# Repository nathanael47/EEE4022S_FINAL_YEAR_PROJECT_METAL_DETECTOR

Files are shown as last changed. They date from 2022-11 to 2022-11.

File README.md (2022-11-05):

# EEE4022S_FINAL_YEAR_PROJECT_METAL_DETECTOR
This is the git repository for all code my design and implementation of a metal detector

# PROJECT NAME: DESIGN AND IMPLEMENTATION OF A METAL DETECTOR

# DESCRIPTION:
This is the design and implementation of a metal detector that can detect metals and distinguish if it is ferrous or non ferrous

# INSTALLATION
1. Download the zip version of the repository.
2. Alternatively, pull the repository using the following line;

# USAGE
Prototype:
1. Install arduino and teensyduino
2. Run any of the implementations.
3. Run Metal_Detector.ino

# CREDITS: Done by NATHANAEL GEORGE THOMAS-5/11/2022

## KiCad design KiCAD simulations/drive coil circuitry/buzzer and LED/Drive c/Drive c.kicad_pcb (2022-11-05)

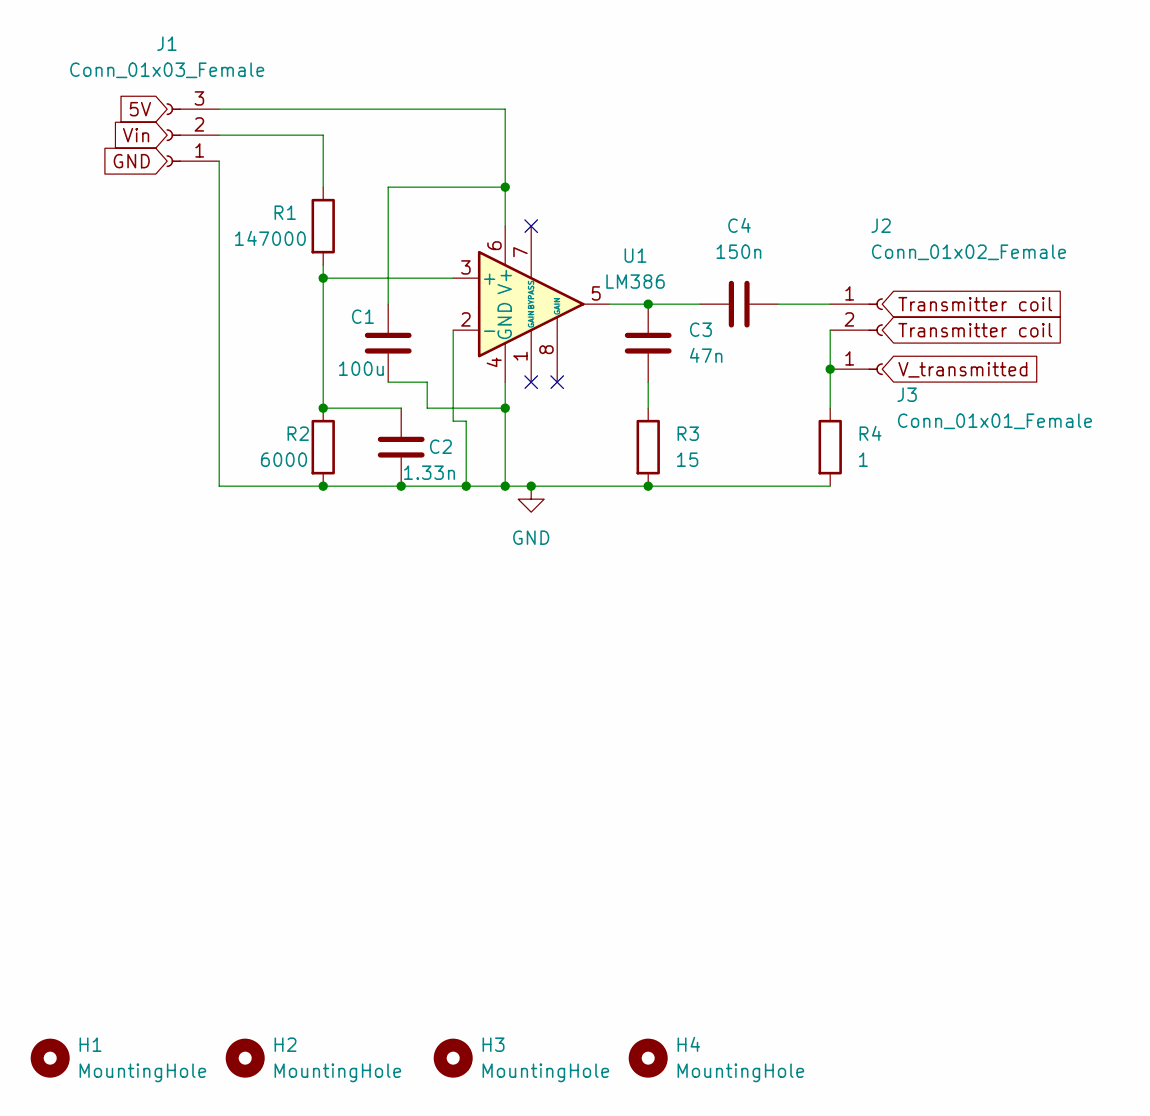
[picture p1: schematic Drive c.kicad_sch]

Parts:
C1: 100u; CP_Radial_D7.5mm_P2.50mm
C2: 1.33n; CP_Radial_D7.5mm_P2.50mm
C3: 47n; CP_Radial_D7.5mm_P2.50mm
C4: 150n; CP_Radial_D7.5mm_P2.50mm
H1, H2, H3, H4: MountingHole; MountingHole_2.7mm_M2.5_ISO14580_Pad_TopOnly
J1: Conn_01x03_Female; PinSocket_1x03_P2.54mm_Vertical
J2: Conn_01x02_Female; PinSocket_1x02_P2.54mm_Vertical
J3: Conn_01x01_Female; PinSocket_1x01_P2.54mm_Vertical
R1: 147000; R_Axial_DIN0309_L9.0mm_D3.2mm_P12.70mm_Horizontal
R2: 6000; R_Axial_DIN0309_L9.0mm_D3.2mm_P12.70mm_Horizontal
R3: 15; R_Axial_DIN0309_L9.0mm_D3.2mm_P12.70mm_Horizontal
R4: 1; R_Axial_DIN0309_L9.0mm_D3.2mm_P12.70mm_Horizontal
U1: LM386; DIP-8_W7.62mm

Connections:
GND: C1.2, C2.2, J1.1, R2.2, R3.2, R4.2, U1.2 (-), U1.4 (GND)
unnamed: C1.1, J1.3, U1.6 (V+)
unnamed: C2.1, R1.2, R2.1, U1.3 (+)
unnamed: C3.1, R3.1
unnamed: C3.2, C4.1, U1.5
unnamed: C4.2, J2.1
unnamed: J1.2, R1.1
unnamed: J2.2, J3.1, R4.1

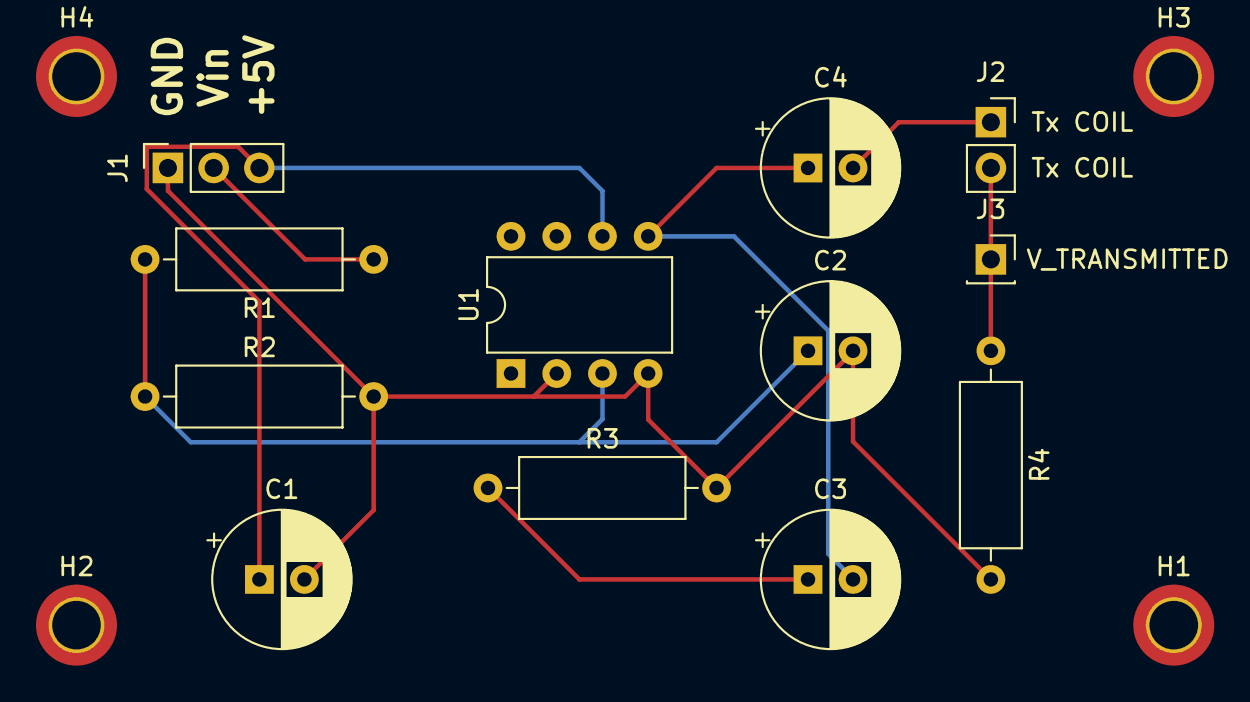
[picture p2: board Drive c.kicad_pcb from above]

Board: 2 copper layers, 16 parts (0 on the bottom side), 8 nets.

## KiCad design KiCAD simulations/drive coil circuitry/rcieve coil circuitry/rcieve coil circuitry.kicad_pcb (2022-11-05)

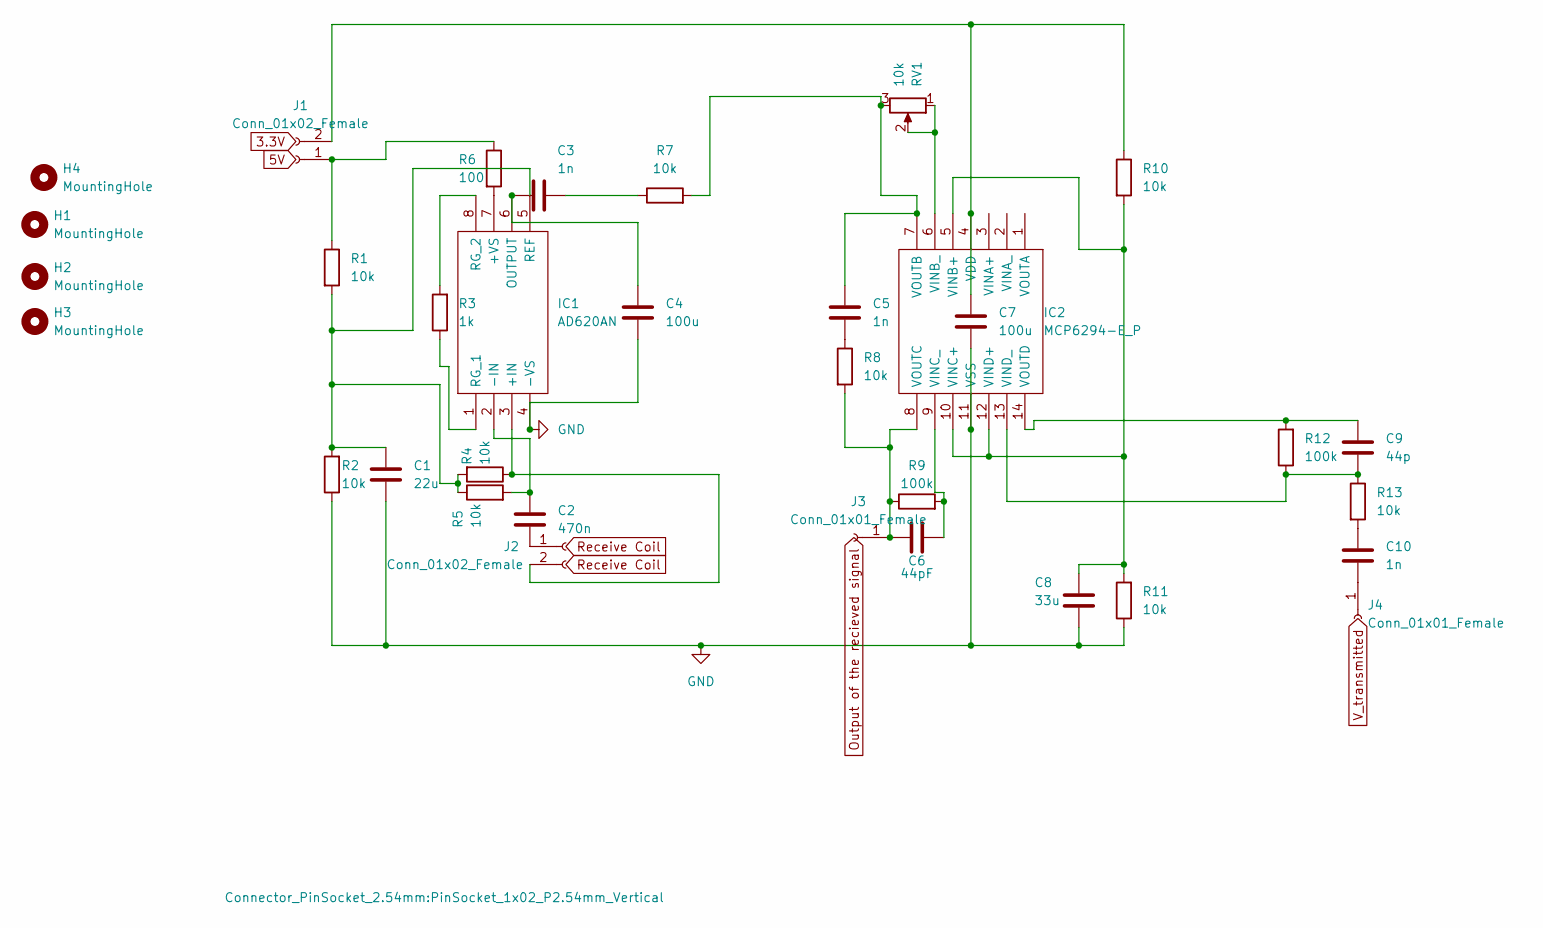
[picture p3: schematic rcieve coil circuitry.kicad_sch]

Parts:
C1: 22u; C_Rect_L4.6mm_W3.8mm_P2.50mm_MKS02_FKP02
C2: 470n; C_Rect_L7.0mm_W4.5mm_P5.00mm
C3: 1n; C_Rect_L7.0mm_W6.5mm_P5.00mm
C4: 100u; C_Radial_D10.0mm_H12.5mm_P5.00mm
C5: 1n; C_Rect_L4.6mm_W3.0mm_P2.50mm_MKS02_FKP02
C6: 44pF; C_Rect_L4.6mm_W2.0mm_P2.50mm_MKS02_FKP02
C7: 100u; C_Radial_D6.3mm_H5.0mm_P2.50mm
C8: 33u; C_Radial_D6.3mm_H5.0mm_P2.50mm
C9: 44p; C_Rect_L4.0mm_W2.5mm_P2.50mm
C10: 1n; C_Rect_L4.0mm_W2.5mm_P2.50mm
H1, H2, H3, H4: MountingHole; MountingHole_2.2mm_M2
IC1: AD620AN; DIP-8_W7.62mm_LongPads; Manufacturer_Part_Number AD620AN; Mouser Part Number 584-AD620AN
IC2: MCP6294-E_P; DIP-14_W7.62mm_LongPads; Manufacturer_Part_Number MCP6294-E/P; Mouser Part Number 579-MCP6294-E/P
J1, J2: Conn_01x02_Female; PinSocket_1x02_P2.54mm_Vertical
J3, J4: Conn_01x01_Female; PinSocket_1x01_P2.54mm_Vertical
R1, R2: 10k; R_Axial_DIN0309_L9.0mm_D3.2mm_P5.08mm_Vertical
R3: 1k; R_Axial_DIN0309_L9.0mm_D3.2mm_P5.08mm_Vertical
R4, R5, R7, R8, R10, R11: 10k; R_Axial_DIN0614_L14.3mm_D5.7mm_P15.24mm_Horizontal
R6: 100; R_Axial_DIN0614_L14.3mm_D5.7mm_P15.24mm_Horizontal
R9: 100k; R_Axial_DIN0614_L14.3mm_D5.7mm_P15.24mm_Horizontal
R12: 100k; R_Axial_DIN0414_L11.9mm_D4.5mm_P15.24mm_Horizontal
R13: 10k; R_Axial_DIN0414_L11.9mm_D4.5mm_P15.24mm_Horizontal
RV1: 10k; Potentiometer_Alps_RK09K_Single_Vertical

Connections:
GND: C1.2, C4.2, C7.2, C8.2, IC1.4 (-VS), IC2.11 (VSS), R2.1, R11.1
unnamed: C1.1, IC1.5 (REF), R1.2, R2.2, R4.2, R5.1
unnamed: C2.1, IC1.2 (-IN), R5.2
unnamed: C2.2, J2.1
unnamed: C3.1, C4.1, IC1.6 (OUTPUT)
unnamed: C3.2, R7.1
unnamed: C5.1, IC2.7 (VOUTB), R7.2, RV1.3
unnamed: C5.2, R8.1
unnamed: C6.1, IC2.8 (VOUTC), J3.1, R8.2, R9.1
unnamed: C6.2, IC2.9 (VINC_), R9.2
unnamed: C8.1, IC2.5 (VINB+), IC2.10 (VINC+), IC2.12 (VIND+), R10.2, R11.2
unnamed: C9.1, IC2.14 (VOUTD), R12.2
unnamed: C9.2, IC2.13 (VIND_), R12.1, R13.1
unnamed: C10.1, R13.2
unnamed: C10.2, J4.1
unnamed: IC1.1 (RG_1), R3.1
unnamed: IC1.3 (+IN), J2.2, R4.1
unnamed: IC1.7 (+VS), R6.2
unnamed: IC1.8 (RG_2), R3.2
unnamed: IC2.6 (VINB_), RV1.1, RV1.2
unnamed: J1.1, R1.1, R6.1
unnamed: C7.1, IC2.4 (VDD), J1.2, R10.1

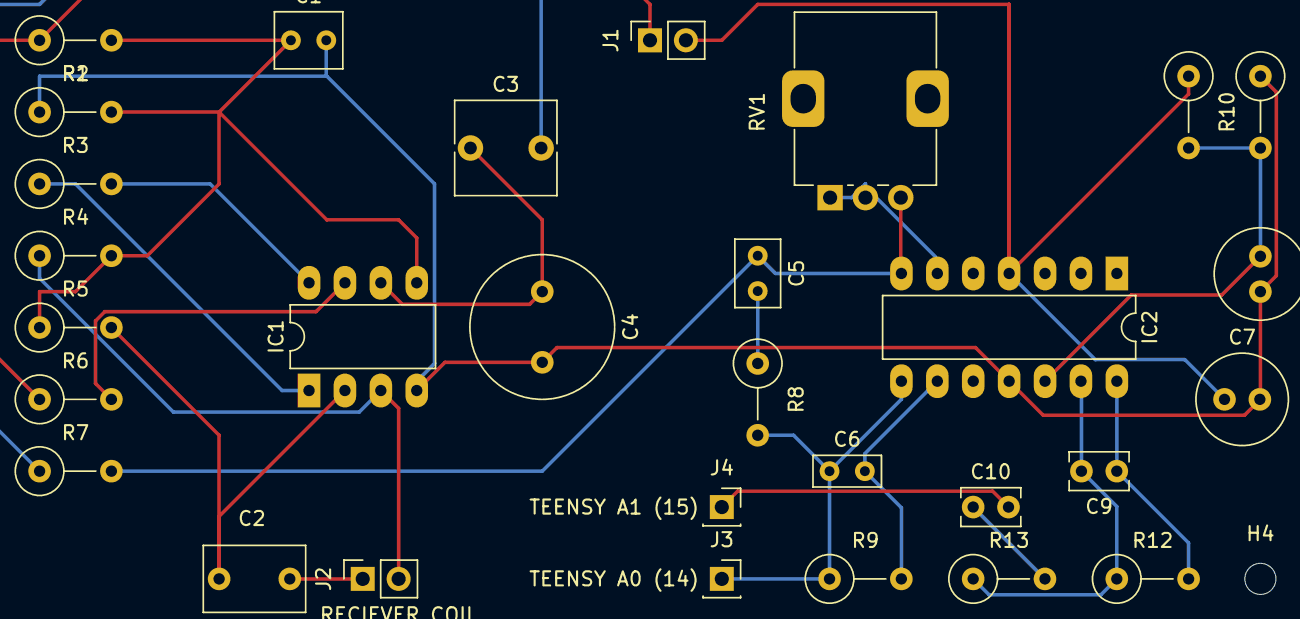
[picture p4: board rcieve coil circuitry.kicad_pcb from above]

Board: 2 copper layers, 34 parts (0 on the bottom side), 22 nets.

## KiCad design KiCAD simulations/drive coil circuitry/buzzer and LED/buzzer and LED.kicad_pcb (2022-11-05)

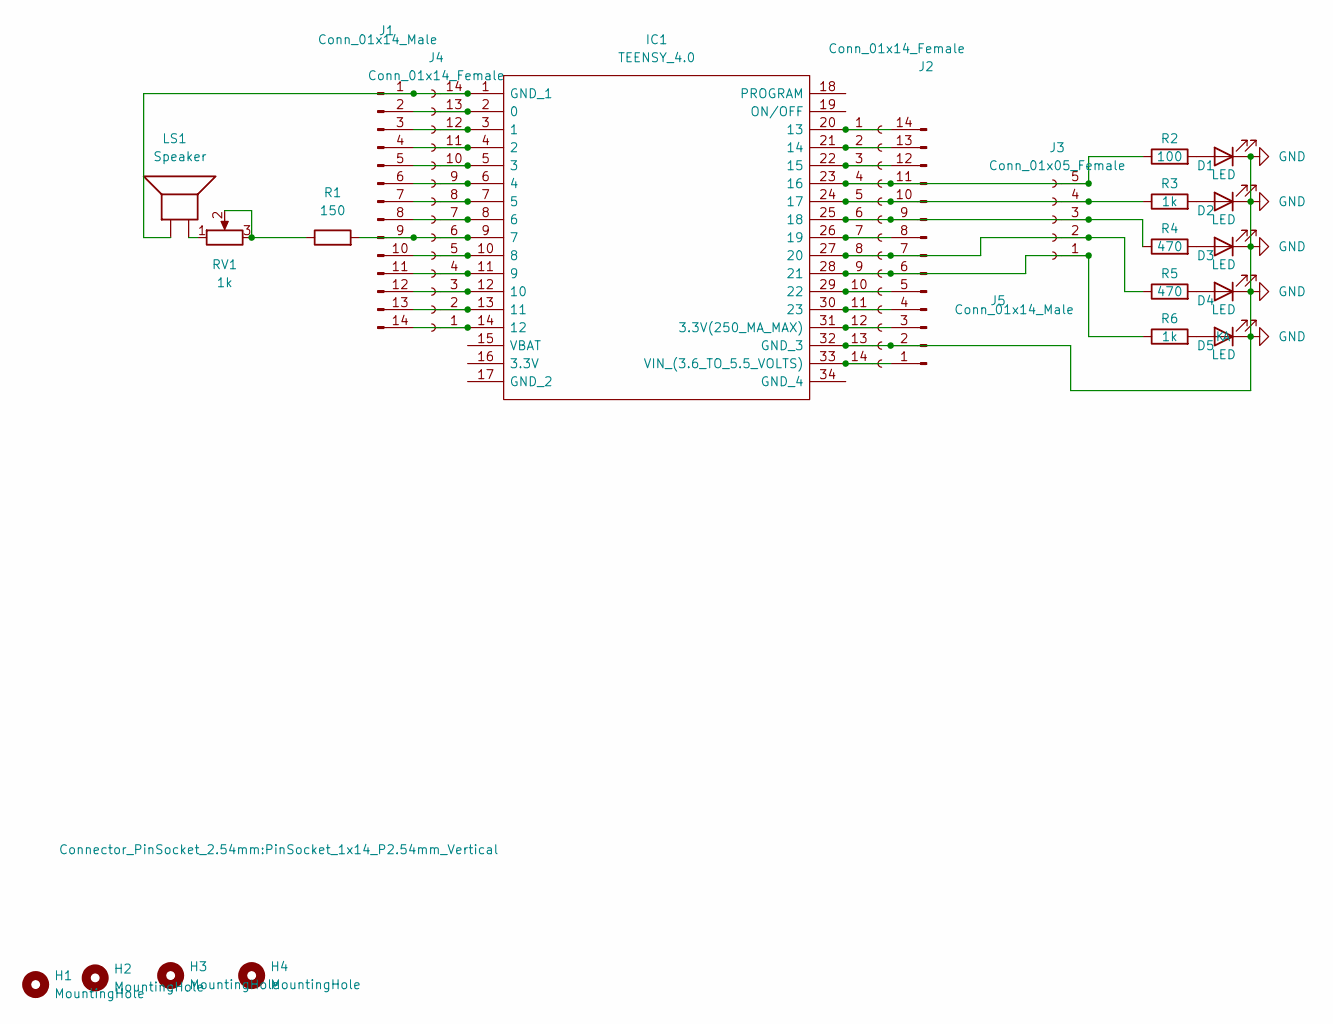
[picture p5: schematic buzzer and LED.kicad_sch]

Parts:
D1, D2, D3, D4: LED; LED_D3.0mm_Clear
D5: LED; LED_D3.0mm
H1, H2, H3, H4: MountingHole; MountingHole_2.1mm
IC1: TEENSY_4.0; TEENSY40; Manufacturer_Part_Number TEENSY 4.0
J1, J2: Conn_01x14_Male; PinHeader_1x14_P2.54mm_Vertical
J3: Conn_01x05_Female; PinSocket_1x05_P1.27mm_Vertical
J4, J5: Conn_01x14_Female; PinSocket_1x14_P2.54mm_Vertical
LS1: Speaker; Buzzer_12x9.5RM7.6
R1: 150; R_Axial_DIN0207_L6.3mm_D2.5mm_P5.08mm_Vertical
R2: 100; R_Axial_DIN0207_L6.3mm_D2.5mm_P5.08mm_Vertical
R3, R6: 1k; R_Axial_DIN0207_L6.3mm_D2.5mm_P5.08mm_Vertical
R4, R5: 470; R_Axial_DIN0207_L6.3mm_D2.5mm_P5.08mm_Vertical
RV1: 1k; Potentiometer_Alps_RK163_Single_Horizontal

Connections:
unnamed: D1.2 (A), R2.2
unnamed: D2.2 (A), R3.2
unnamed: D3.2 (A), R4.2
unnamed: D4.2 (A), R5.2
unnamed: D5.2 (A), R6.2
unnamed: IC1.1 (GND_1), J1.1, J4.14, LS1.1
unnamed: IC1.2 (0), J1.2, J4.13
unnamed: IC1.3 (1), J1.3, J4.12
unnamed: IC1.4 (2), J1.4, J4.11
unnamed: IC1.5 (3), J1.5, J4.10
unnamed: IC1.6 (4), J1.6, J4.9
unnamed: IC1.7 (5), J1.7, J4.8
unnamed: IC1.8 (6), J1.8, J4.7
unnamed: IC1.9 (7), J1.9, J4.6, R1.2
unnamed: IC1.10 (8), J1.10, J4.5
unnamed: IC1.11 (9), J1.11, J4.4
unnamed: IC1.12 (10), J1.12, J4.3
unnamed: IC1.13 (11), J1.13, J4.2
unnamed: IC1.14 (12), J1.14, J4.1
unnamed: IC1.20 (13), J2.14, J5.1
unnamed: IC1.21 (14), J2.13, J5.2
unnamed: IC1.22 (15), J2.12, J5.3
unnamed: IC1.23 (16), J2.11, J3.5, J5.4, R2.1
unnamed: IC1.24 (17), J2.10, J3.4, J5.5, R3.1
unnamed: IC1.25 (18), J2.9, J3.3, J5.6, R4.1
unnamed: IC1.26 (19), J2.8, J5.7
unnamed: IC1.27 (20), J2.7, J3.2, J5.8, R5.1
unnamed: IC1.28 (21), J2.6, J3.1, J5.9, R6.1
unnamed: IC1.29 (22), J2.5, J5.10
unnamed: IC1.30 (23), J2.4, J5.11
unnamed: IC1.31 (3.3V(250_MA_MAX)), J2.3, J5.12
unnamed: IC1.33 (VIN_(3.6_TO_5.5_VOLTS)), J2.1, J5.14
unnamed: LS1.2, RV1.1
unnamed: R1.1, RV1.2, RV1.3

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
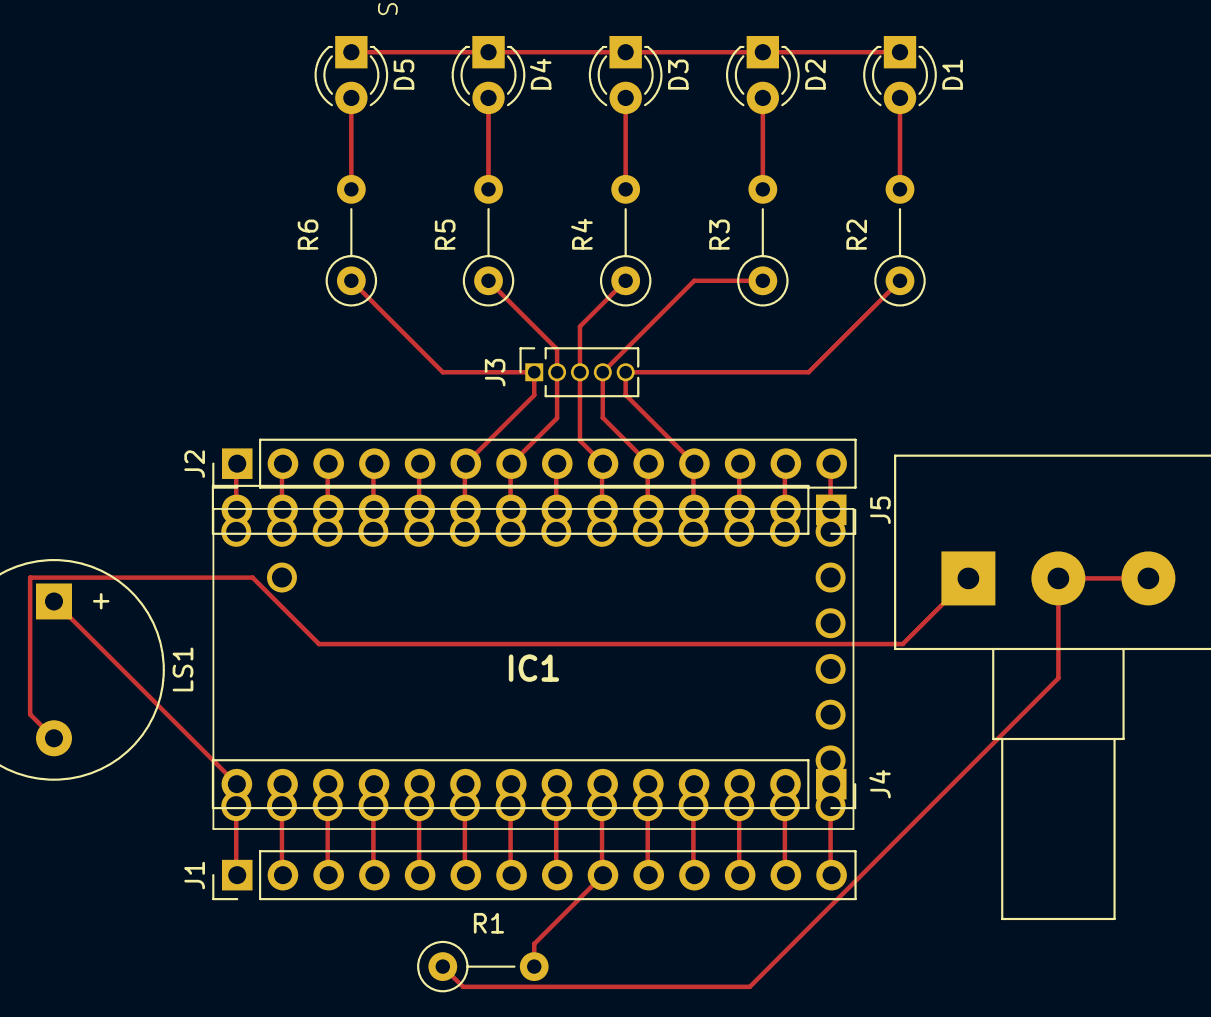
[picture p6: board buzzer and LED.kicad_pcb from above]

Board: 2 copper layers, 23 parts (0 on the bottom side), 36 nets.

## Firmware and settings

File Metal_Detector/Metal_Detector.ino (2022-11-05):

#include <ADC.h>
#include <math.h>
int n_test = 1000;                        //the number of samples we are going to take at one go 
int n; 
const int n_max = 1620;
int driveCoil = 6;                       //defining which pin the drive coil circuitry will be attached to 
//setting up the sine and cosine waves
const float pi = 3.14159267;             //initiating a value for pi 
int rA0[n_max];
int rA1[n_max];
int buzzer = 9;                          //initialising the pin on which the buzzer is attached to
float f0 = 20000;                        //setting the frequency of 20kHz 
int t0 = (1/f0)*pow(10,6);               //finding how long one cycle will take at 20kHz
float w = 2*pi*f0;

//LED pin setup 
int RLED = 18;
int OLED = 17;
int YLED = 16;
int GLED = 20;
int WLED = 21;

int noBit = 12;
//variable to store the value of I and Q for both the received and transmitted signals
//received signal 
float I_rx = 0;
float Q_rx = 0;
//transmitted signal
float I_tx = 0;
float Q_tx = 0;  

float freq;                               //variable to hold a value of frequency which is used to change the buzzers pwm frequency
float f_sample;                           //used to store the sampling frequency
float t_sample;                           //used to store the period of the sampling frequency 
float phaseShift;
float samplingTime = 10;                  //time in milliseconds

float amp_ref;                            //placeholder for the value of the reference amplitude
float phase_ref;                          //placeholder for the value of the reference phase
int nRef = 10;                            //how many times the code should run during calibration
float Iref;                               //placeholder for the value of the reference I value
float Qref;                               //placeholder for the value of the reference Q value

void setup() {
  // put your setup code here, to run once:
  
  analogWriteFrequency(driveCoil, 20000);   //setting the frequency to 20kHz 
  analogReadResolution(noBit); // Can be 8, 10, 12, 16
  analogReadAveraging(1); // can be 1, 2, 4, 8, 16 or 32
  analogReference(0); // Voltage reference
  Serial.begin(9600);

  //setting up the pinModes used in the metal detector
  pinMode(driveCoil, OUTPUT);               //setting the pin to an output       
  pinMode(A0, INPUT);                       //setting A0 as an input pin to recieve signals 
  pinMode(A1, INPUT);                       //setting A0 as an input pin to recieve a signal
  analogWrite(driveCoil, 127);              //Setting a PWM signal with a 50% duty cycle
  
  //LED setup
  pinMode(RLED, OUTPUT);
  pinMode(OLED, OUTPUT);
  pinMode(GLED, OUTPUT);
  pinMode(YLED, OUTPUT);
  pinMode(WLED, OUTPUT);
  digitalWrite(WLED, HIGH);

  //getting the sample rate frequency to be used to generate the sine and cos waves 
  for (int i =0; i<10; i++){
    f_sample = RateSampling();
  }
  t_sample = 1/f_sample;

  n = round((samplingTime*pow(10,-3))/t_sample);

  phaseShift =(f0/f_sample)*(360/2);
  ref();
//  Serial.println(amp_ref);
//  Serial.println(phase_ref); 
}

float ref(){
   amp_ref = 0; 
   phase_ref = 0; 
   for(int j=0; j<nRef; j++){
     for(int i = 0; i<n; i++){
      rA0[i] = analogRead(A0);
      rA1[i] = analogRead(A1);  
     }
     for(int j = 0; j<n; j++){
         float x_v = 3.3*(rA0[j]/pow(2,noBit))-1.65;      //converting the bit value of the received signal to a voltage
         float x_tx = 3.3*(rA1[j]/pow(2,noBit))-1.65;    //converting the bit value of the transmitted signal to a voltage
         I_rx = I_rx + x_v*(2*cos(w*j*t_sample));
         Q_rx = Q_rx + x_v*(-2*sin(w*j*t_sample));
    
         I_tx = I_tx + x_tx*(2*cos(w*j*t_sample));
         Q_tx = Q_tx + x_tx*(-2*sin(w*j*t_sample));
      }
      //Simulating a low pass filter through weighted average
      float I_filt = I_rx/n;                     //getting the weighted average of the I for the recieved signal.  
      float Q_filt = Q_rx/n;                     //getting the weighted average of the Q for the recieved signal. 
    
      float I_filt_tx = I_tx/n;                  //getting the weighted average of the I for the transmitted signal. 
      float Q_filt_tx = Q_tx/n;                  //getting the weighted average of the Q for the transmitted signal.
    
      float amp_rx = sqrt((I_filt*I_filt)+(Q_filt*Q_filt));      //finding the amplitude of the received signal 
      
      float ang_rx = atan2(Q_filt, I_filt);          //finding the phase of the received signal 
      
      float amp_tx = sqrt((I_filt_tx*I_filt_tx)+(Q_filt_tx*Q_filt_tx)); //finding the amplitude of the transmitted signal 
      float ang_tx = atan2(Q_filt_tx, I_filt_tx);    //finding the phase of the transmitted signal
    
      float phaseDiff = ang_tx-ang_rx - phaseShift;
      float amp = amp_rx/amp_tx;

      //case if the phase is a negative number
      if(phaseDiff<0){
          phaseDiff = 360 + phaseDiff;  
      }
      else{
          phaseDiff = phaseDiff;  
      }
      amp_ref = amp_ref + amp; 
      phase_ref = phase_ref + phaseDiff;
   }
   amp_ref = amp_ref/nRef; 
   phase_ref = phase_ref/nRef;
   //getting the I and Q values 
   Iref = amp_ref*cos(phase_ref);
   Qref = amp_ref*sin(phase_ref);

}


//function to get the sample rate frequency of the analog reads 
float RateSampling(){
  float start = micros();
  int t1;
  t1 = micros();    //getting the time
  for(int i =0; i <n_test;i++){
    int x = analogRead(A0);                 //Reading in the received signal on the recieve coil                                         
    int x_tx = analogRead(A1);              //Reading in the current through the coil 
  }
  float t2 = micros(); 
  float t_total = t2-t1;                    //getting the time it takes
  float f_rate = 1/((t_total*pow(10,-6))/n_test); //frequency relating to the time taken
  //Serial.println(t_total);
//  Serial.println(f_rate);
  return f_rate;
}



void loop() {
  // put your main code here, to run repeatedly
  //reading the transmitted and received signal
  for(int i = 0; i<n; i++){
    rA0[i] = analogRead(A0);
    rA1[i] = analogRead(A1);  
  }
  for(int j = 0; j<n; j++){
     float x_v = 3.3*(rA0[j]/pow(2,noBit))-1.65;          //converting the bit value of the received signal to a voltage
     float x_tx = 3.3*(rA1[j]/pow(2,noBit))-1.65;    //converting the bit value of the transmitted signal to a voltage
     I_rx = I_rx + x_v*(2*cos(w*j*t_sample));
     Q_rx = Q_rx + x_v*(-2*sin(w*j*t_sample));

     I_tx = I_tx + x_tx*(2*cos(w*j*t_sample));
     Q_tx = Q_tx + x_tx*(-2*sin(w*j*t_sample));
  }
  //Simulating a low pass filter
  float I_filt = I_rx/n;                     //getting the weighted average of the I for the received signal.   
  float Q_filt = Q_rx/n;                     //getting the weighted average of the Q for the received signal. 
  float I_filt_tx = I_tx/n;                  //getting the weighted average of the I for the transmitted signal. 
  float Q_filt_tx = Q_tx/n;                  //getting the weighted average of the Q for the transmitted signal. 

  float amp_rx = sqrt((I_filt*I_filt)+(Q_filt*Q_filt));      //finding the amplitude of the recieved signal 
  float ang_rx = atan2(Q_filt, I_filt);          //finding the phase of the received signal 
  float amp_tx = sqrt((I_filt_tx*I_filt_tx)+(Q_filt_tx*Q_filt_tx));//finding the amplitude of the transmitted signal 
  float ang_tx = atan2(Q_filt_tx, I_filt_tx);    //finding the phase of the transmitted signal

  float phaseDiff = ang_tx-ang_rx;
  float amp = amp_rx/amp_tx;

  float Inew = amp*cos(phaseDiff);
  float Qnew = amp*sin(phaseDiff);
  float Idiff = Inew - Iref;
  float Qdiff = Qnew - Qref;

  float amp_obj = sqrt((Idiff*Idiff)+(Qdiff*Qdiff));
  float ang_obj = atan2(Qdiff, Idiff); 
  
//  Serial.print("The Amplitude is: ");
//    Serial.println(amp_obj);
//    Serial.println(ang_obj);
//  Serial.print(" The phase difference is: ");
  //case if the phase is a negative number
  ang_obj = ang_obj*180/pi;
  if(ang_obj<0){
      ang_obj = 360 + ang_obj;  
  }
  else{
      ang_obj = ang_obj;  
  }
//  Serial.print(ang_obj);
//  Serial.print(" ");
//  Serial.println(phaseDiff);
//    Serial.println(f_sample);
   //function to generate the value to be played through the speaker
   float amp_obj_sound = (pow(amp_obj,0.25)/pow(1.5,0.25))*1.5;
//   Serial.println(amp_obj);
    
   freq=map(amp_obj_sound,0,1.5,1,1000);      //mapping the calculated value to a frequency
   tone(buzzer,freq);                         //generating asound on the speaker
  //logic statements to determine what the LEDs need to turn on when 
  if(amp_obj>0.04 and amp_obj < 1.54){
    digitalWrite(YLED, HIGH);
    if(amp_obj>0.6 and amp_obj< 1.54){
     //FERROUS MATERIALS 
     if(ang_obj>5 and ang_obj<20){
        digitalWrite(OLED, HIGH);
        digitalWrite(GLED, LOW);     
     }
     else if(ang_obj>30 and ang_obj<40){
        digitalWrite(OLED, HIGH);
        digitalWrite(GLED, LOW);     
     }
     else if(ang_obj>50 and ang_obj<69){
        digitalWrite(OLED, HIGH);
        digitalWrite(GLED, LOW);     
     }
     else if(ang_obj>77 and ang_obj<86){
        digitalWrite(OLED, HIGH);
        digitalWrite(GLED, LOW);     
     }
     else if(ang_obj>110 and ang_obj<130){
        digitalWrite(OLED, HIGH);
        digitalWrite(GLED, LOW);     
     }
     else if(ang_obj>145 and ang_obj<160){
        digitalWrite(OLED, HIGH);
        digitalWrite(GLED, LOW);     
     }
     else if(ang_obj>280 and ang_obj<290){
        digitalWrite(OLED, HIGH);
        digitalWrite(GLED, LOW);     
     }
     else if(ang_obj>310 and ang_obj<360){
        digitalWrite(OLED, HIGH);
        digitalWrite(GLED, LOW);     
     }
     
     //NON- FERROUS MATERIALS
     else if(ang_obj>20 and ang_obj<30){
        digitalWrite(GLED, HIGH);
        digitalWrite(OLED, LOW);  
     }
     else if(ang_obj>60 and ang_obj<75){
        digitalWrite(GLED, HIGH);
        digitalWrite(OLED, LOW);  
     }
     else if(ang_obj>90 and ang_obj<110){
        digitalWrite(GLED, HIGH);
        digitalWrite(OLED, LOW);  
     }
     else if(ang_obj>260 and ang_obj<270){
        digitalWrite(GLED, HIGH);
        digitalWrite(OLED, LOW);  
     }
  }}
  //saturation case
  else if(amp_obj>1.55){
    digitalWrite(RLED, HIGH);
    digitalWrite(GLED, LOW);
    digitalWrite(YLED, LOW);
    digitalWrite(OLED, LOW);  
  }
  //no changes
  else{
    digitalWrite(YLED, LOW);
    digitalWrite(GLED, LOW);
    digitalWrite(RLED, LOW);
    digitalWrite(OLED, LOW); 
  }

  //resetting the values 
  I_tx = 0;
  Q_tx = 0;
  I_rx = 0;
  Q_rx = 0;
}
